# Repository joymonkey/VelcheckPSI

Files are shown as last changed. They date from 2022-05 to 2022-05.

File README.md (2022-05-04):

# Velcheck PSI Reproduction Project

**PSI** : Process State Indicator, the round color light seen on R2-D2's dome (one blue/red in front, one yellow/green in rear)

**Velcheck** : Pioneering member of the R2 Builders Club, 80's synth virtuoso

In the early days of the R2 Builders, Mike Velcheck designed and supplied a PSI for club members around the world. His design has been the basis for most PSI's since, all sharing the same footprint, many with an abundance of LEDs and fancy swipe animations, none as simple and plug-n-play friendly as Mikes. In December of 2021 Mike passed away.

This project aims to bring back Mike Velcheck's great PSI design, so that it may continue to make its way into droids. Using a donor unit, I reverse clumgeneered Mike's PCB, making a couple of very minor tweaks to the layout. An unused capacitor was removed, in it's place is a powerful Devo Energy Dome (a nod to Mike's involvement with RadioStar Band). The resulting Eagle PCB and schematic files are found within this repository, along with gerber files for production, firmware .bin and Mike's own instruction manual.

**Usage** 

See Mike's PDF user guide in this repository.

**Through-Hole Assembly**

The boards come partially assembled, but the through-hole components will need to be soldered in place. Before starting, you should decide on your LED layout (see Checkerboard vs Side by Side beloe).

 * Being mindful of polarity and color placement, each LED can then be soldered in place.
 * Next, you'll want to solder the 8-pin IC socket, which the PIC MCU (U1) will eventually sit in.
 * Solder the jumper pins for JP1 and JP2.
 * Solder the 2-pin and 4-pin screw terminals.
 * Carefully insert the pre-programmed PIC MCU into its socket.

To test, apply 12V to the 2-pin screw terminal (being mindful of polarity). 

**Checkerboard vs Side by Side?**

By moving two resistors on the board, it can be configured with LEDs in a checkerboard layout (giving a better 'spead' of each color), or side-by-side layout (which allows the PSI to appear 'stuck' with both red and blue lit at the same time). The board uses 220 ohm ressitors to limit current to each branch of 3 LEDs. For checkerboard layout, R9 and R10 should not be populated. For side-by-side layout, R8 and R5 should not be populated.

**Using with JEDI Displays**

The PIC IC can be removed, and two wires run from a JEDI Display controller. This allows the JEDI Display to set the PSI's to their specific colors (useful during animations) rather than the onboard PIC.

**Bill Of Materials**

The kit should coime will all parts needed, but if you'd like to build from scratch, here is a BOM for all parts. For LEDs, high brightness and 120 degree viewing angle is recommended. For standard R2-D2 colors, you'll need 6 red, 6 blue, 6 yellow, 6 green. In the US, SuperBrightLEDs sell suitable 5m LEDs for about 50c each. These offer better spread of color than typical cheap 5mm LEDs.

 * U1 : PIC10F202-I/P 8-bit MCU (typically in an )
 * U2 : AS78L05RTR-E1 5V LDO
 * C2 : 330nf 50V 0805 X7R capacitor
 * C3 : 100nf 50V 0805 X7R capacitor
 * R1, R2 : 10K ohm 0603 resistor
 * R3, R6 : 3.3K ohm 0603 resistor
 * R4, R5, R7, R8 : 220 ohm 0603 resistor
 * D1-D12 : 5mm LEDs, various colors
 * D13 : 1N4001 diode
 * Q1, Q2 : MBT2222A BJT NPN transistor
 * P1 : 2-pin 2.54mm pitch screw terminal
 * P2 : 4-pin 2.54mm pitch screw terminal
 * JP1 & JP2 : 2.54mm 2-row 2-column male pin header

**Firmware**

The firmware .bin file in this repository was copied directly from one of Mike's PSI's. Unfortunately source code is unavailable. To program a blank PIC IC, you'll need a programmer such as a PicKit3.

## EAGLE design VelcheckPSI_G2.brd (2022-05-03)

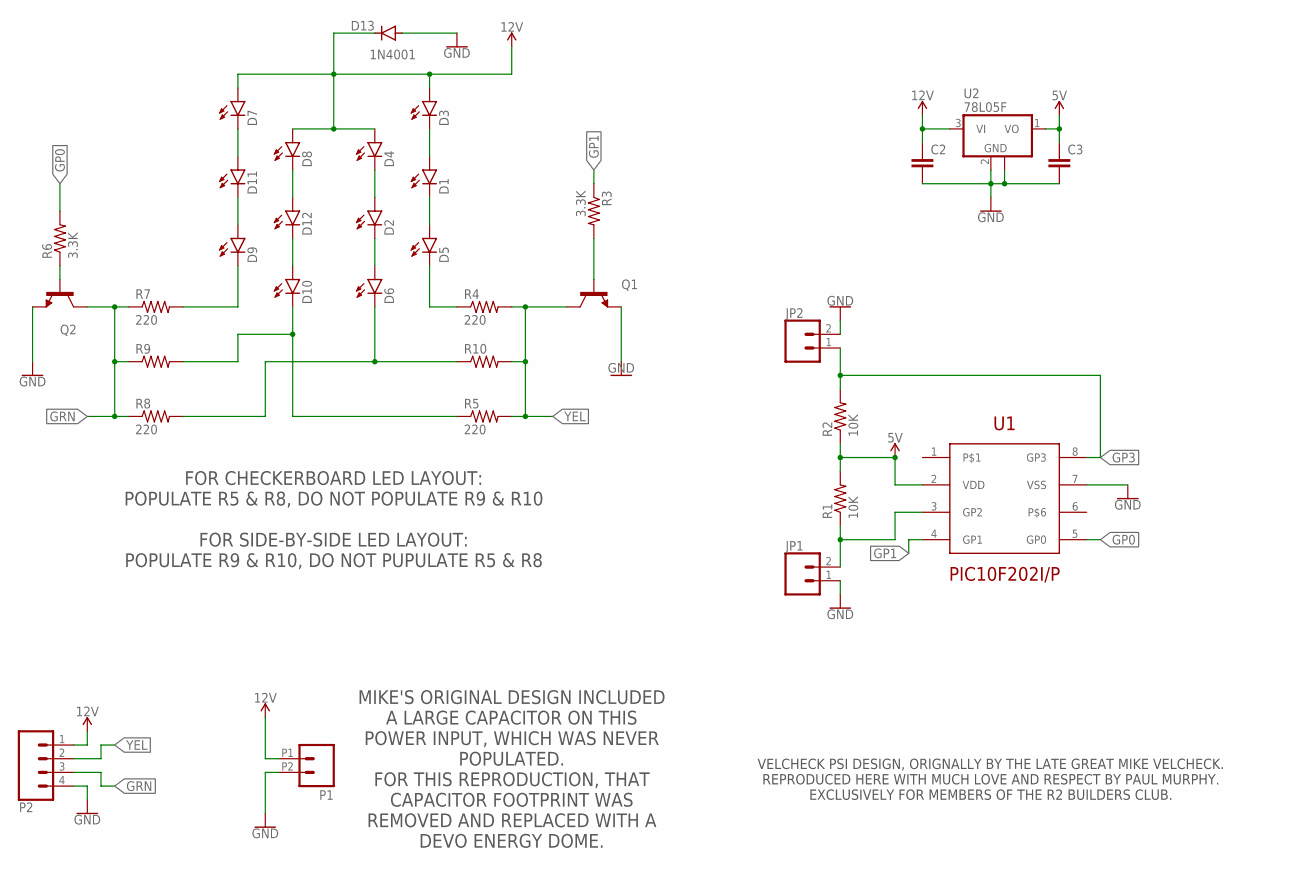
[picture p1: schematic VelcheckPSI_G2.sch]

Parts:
C2, C3: C-EUC0805; C0805
D1, D2, D3, D4, D5, D6, D7, D8, D9, D10, D11, D12: LED5MM; LED5MM_SLIM
D13: 1N4001; DO-214AC
JP1, JP2: CONN_02; 1X02
P1: M022.54MM_SCREWTERM; 1X02_2.54_SCREWTERM
P2: CONN_04POLAR; MOLEX-1X4
Q1, Q2: MMBT2222ALT1-NPN-SOT23-BEC; SOT23-BEC
R1, R2: 10K; R0603
R3, R6: 3.3K; R0603
R4, R5, R7, R8: 220; R0603
R9, R10: R-US_R0603; R0603
U1: PIC10F202I/P; DIP762W53P254L949H508Q8B
U2: 78L05F; SOT89

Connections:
5V: C3.1, R1.2, R2.1, U1.2 (VDD), U2.1 (VO)
12V: C2.1, D3.A, D4.A, D7.A, D8.A, D13.C, P1.P1 (1), P2.1, U2.3 (VI)
GND: C2.2, C3.2, D13.A, JP1.1, JP2.2, P1.P2 (2), P2.4, Q1.E, Q2.E, U1.7 (VSS), U2.2 (GND), U2.2@1 (GND)
GP0: R6.2, U1.5 (GP0)
GP1: R3.1, U1.4 (GP1)
GP3: JP2.1, R2.2, U1.8 (GP3)
GRN: P2.3, Q2.C, R7.1, R8.1, R9.1
unnamed: Q2.B, R6.1
unnamed: Q1.B, R3.2
unnamed: JP1.2, R1.1, U1.3 (GP2)
unnamed: D5.K (C), R4.1
unnamed: D9.K (C), R7.2
unnamed: D10.K (C), R5.1, R9.2
unnamed: D1.A, D3.K (C)
unnamed: D2.A, D4.K (C)
unnamed: D1.K (C), D5.A
unnamed: D2.K (C), D6.A
unnamed: D6.K (C), R8.2, R10.1
unnamed: D7.K (C), D11.A
unnamed: D9.A, D11.K (C)
unnamed: D8.K (C), D12.A
unnamed: D10.A, D12.K (C)
YEL: P2.2, Q1.C, R4.2, R5.2, R10.2

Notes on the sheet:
FOR CHECKERBOARD LED LAYOUT: POPULATE R5 & R8, DO NOT POPULATE R9 & R10 FOR SIDE-BY-SIDE LED LAYOUT: POPULATE R9 & R10, DO NOT PUPULATE R5 & R8
MIKE'S ORIGINAL DESIGN INCLUDED A LARGE CAPACITOR ON THIS POWER INPUT, WHICH WAS NEVER POPULATED. FOR THIS REPRODUCTION, THAT CAPACITOR FOOTPRINT WAS REMOVED AND REPLACED WITH A DEVO ENERGY DOME.
VELCHECK PSI DESIGN, ORIGNALLY BY THE LATE GREAT MIKE VELCHECK. REPRODUCED HERE WITH MUCH LOVE AND RESPECT BY PAUL MURPHY. EXCLUSIVELY FOR MEMBERS OF THE R2 BUILDERS CLUB.

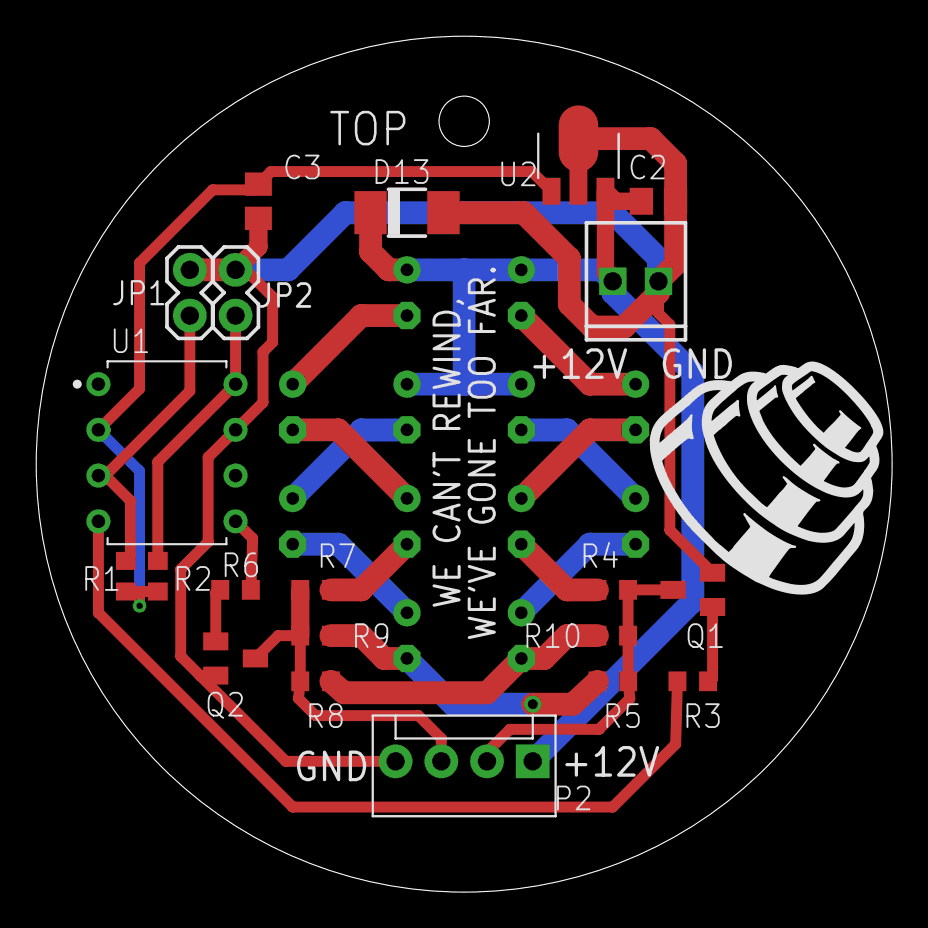
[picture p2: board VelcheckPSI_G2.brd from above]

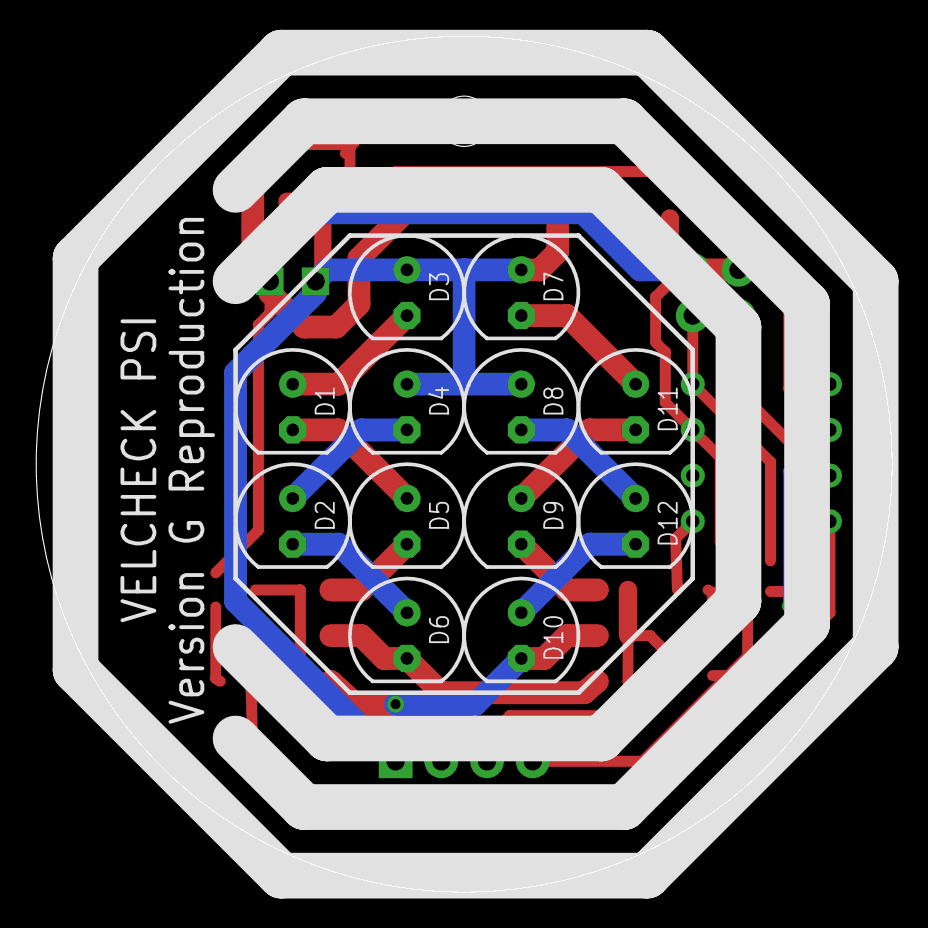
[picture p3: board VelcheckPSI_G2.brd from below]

Board: 2 copper layers, 47.5 x 47.5 mm, 34 parts (12 on the bottom side), 23 nets.

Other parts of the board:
U$1: DEVO

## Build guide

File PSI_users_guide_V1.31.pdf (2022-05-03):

# PSI User's Guide

Version 1.31
February 5, 2008
Mike Velcheck

# 1. Introduction

Thank you for purchasing my "Astromech PSI Kit." These boards are my first electronic contribution to the R2 Builders Club. They were designed with several goals in mind:
1) To create PSIs with a "random-looking" flash pattern
2) To create PSIs which can flash or fade
3) To use high-brightness LEDs
4) To use wide-angle LEDs to minimize "hot spots"
5) To create round PSI boards that can be mounted in a tube
6) To create a fully assembled kit for less than $50, including domestic shipping

# 2. Getting started

Required Tools and materials:
- Small common screwdriver
- Wire strippers
- Wire cutters
- 12V DC source (battery or DC power supply)

Kit Contents:
Your PSI kit contains two PSIs, mode selection shunts (jumpers), and connection wires.

In a standard PSI kit, the front (red/blue) PSI contains the "brains" of the system, and will be referred to as the "master" PSI. The rear (yellow/green) PSI does not contain any control electronics, and is referred to as the "slave" PSI.

The wires have been twisted to form two cables. A standard PSI kit contains a two-wire (red & black)
POWER CABLE and a three-wire (red, yellow, and green) MASTER/SLAVE CABLE.

The shunts are used to control the operating mode of the PSIs, and will be explained in more detail later.

## 2a. Connecting the front and rear PSIs

The front (red/blue) PSI contains the "brains" of the system, and will be referred to as the "master" PSI. The rear (yellow/green) PSI does not contain any control electronics, and is referred to as the "slave" PSI.

PSI User's Guide | Page 1 of 6

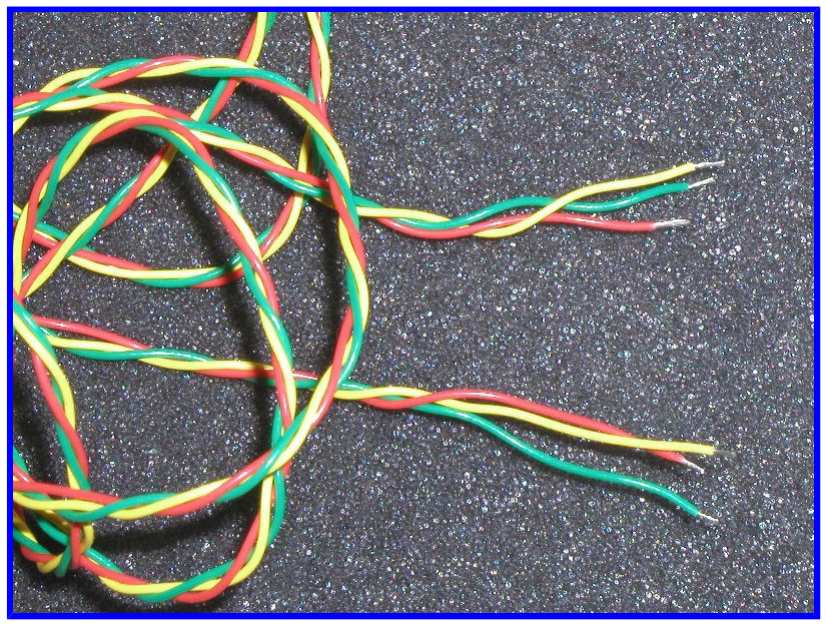
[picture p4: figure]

1) Strip off about 1/8" of insulation from all three wires on both ends of the MASTER/SLAVE CABLE:
2) Loosen the terminals of the four pin connector (J2) on both the MASTER board and the
SLAVE board by turning the screws counter-clockwise.

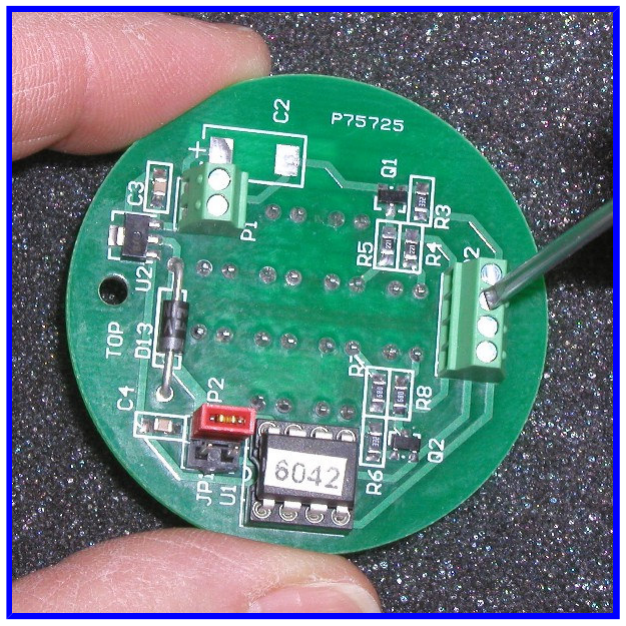
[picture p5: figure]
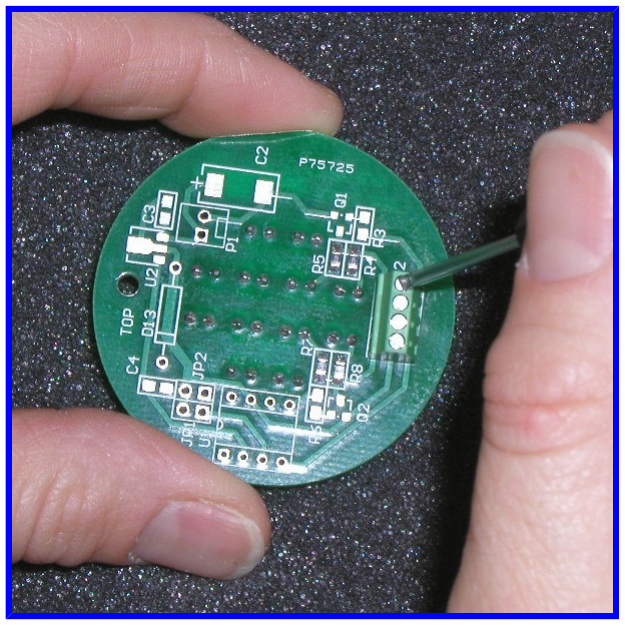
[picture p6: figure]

Master Board | Slave Board
3) Insert the stripped wires into the four pin connector (J2) on the MASTER board and tighten the screw terminals by turning the screws clockwise.

Be sure to match the color and location of each wire (RED, YELLOW, GREEN, NONE) in the picture. Note that the fourth position ("GND") is not used.

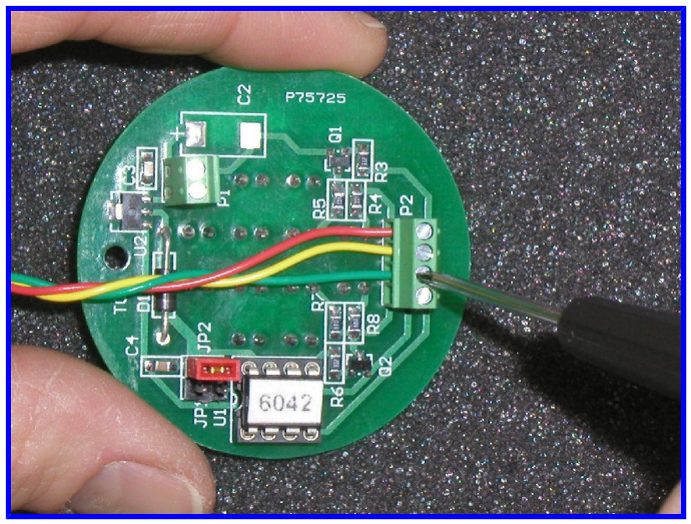
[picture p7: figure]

Master Board

4) Repeat for the matching connector (J2) on the SLAVE board, making certain that the wire locations match in both connectors. Again, note that the fourth position ("GND") is not used.

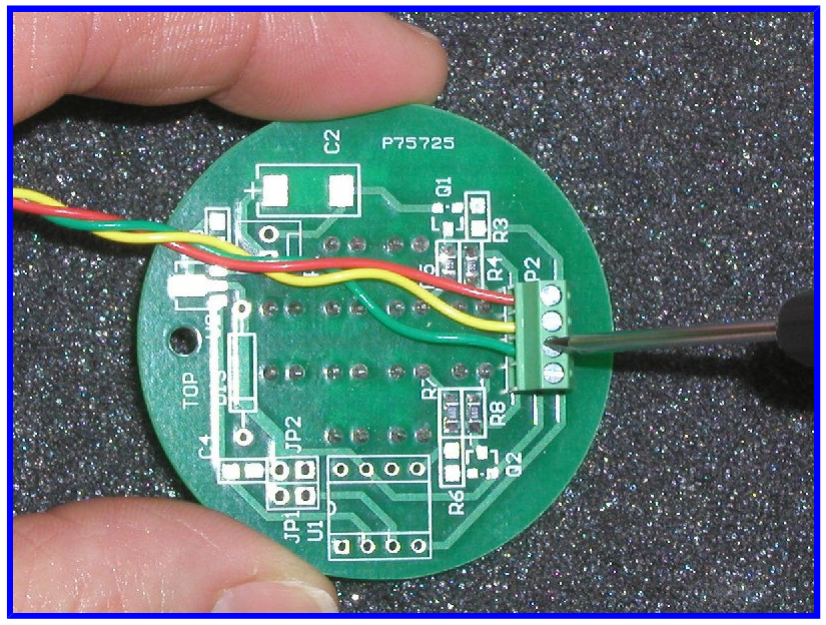
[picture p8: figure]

Slave Board

PSI User's Guide | Page 2 of 6

WARNING!

Never connect a "master" board to another "master" board. If your kit contains two master boards, you should connect each board to a power source, and not to the other board. I don't believe that anything will fry, but you'll be attempting to drive the LEDs from two different sources.

## 2b. Connecting the Power Cable

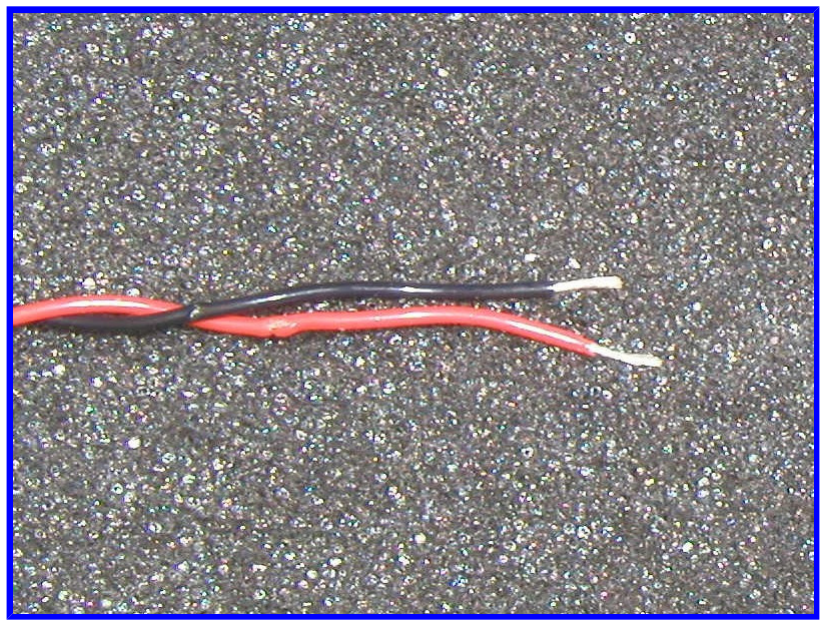
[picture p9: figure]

1) Strip off about 1/8" of insulation from both wires on one end of the POWER CABLE:

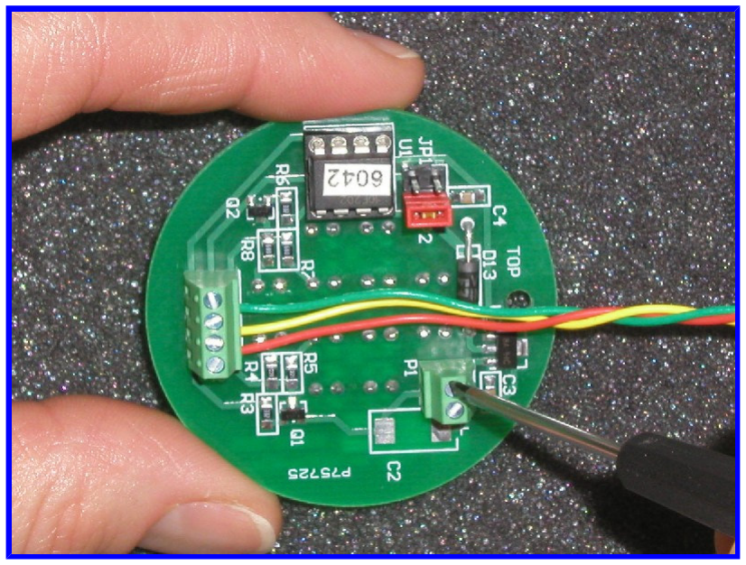
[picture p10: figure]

2) Loosen the terminals of the two-pin connector (J1) on the MASTER board by turning the screws counter-clockwise.
3) Insert the stripped wires (RED = +12V, BLACK = GND) into the two-pin connector (J1) on the MASTER board and tighten the screw terminals by turning the screws clockwise.

Be sure to match the color and location of each wire (RED, BLACK) in the picture.

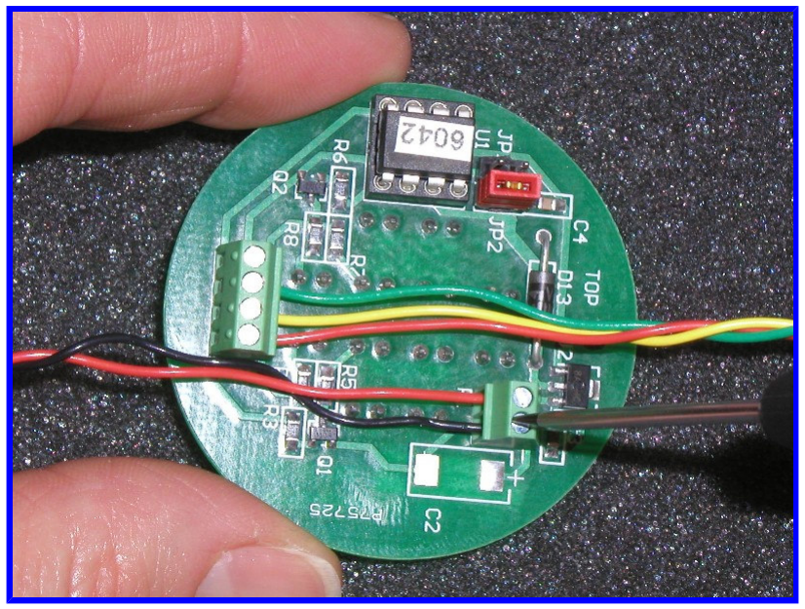
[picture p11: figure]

4) Strip off the insulation from the other end of the power cable to suit your wiring configuration.
5) Connect the stripped wires to the battery or DC power source, making sure that the RED wire is connected to +12V (or BATTERY+), and the BLACK wire is connected to GROUND (or BATTERY-).
PSI User's Guide | Page 3 of 6

# 3. Operating Modes

These PSIs use a microcontroller to control the flash rate and pattern, to create a psudo-random behavior. The boards can operate in one of four modes, controlled by installing different combinations of shunts on jumpers JP1 and JP2. The four modes of operation are:

1) FLASH mode (no shunts) - colors change by blinking back and forth.
2) FADE mode (shunt on JP1) - colors change by fading back and forth.
3) FLASH+FADE (mixed) mode (shunt on JP2) - colors change by a combination of blinking and fading.
4) TEST mode (shunts on JP1 and JP2) - colors FLASH slowly, to allow you to verify each LED is operating properly, or to help with placement of diffuser material.

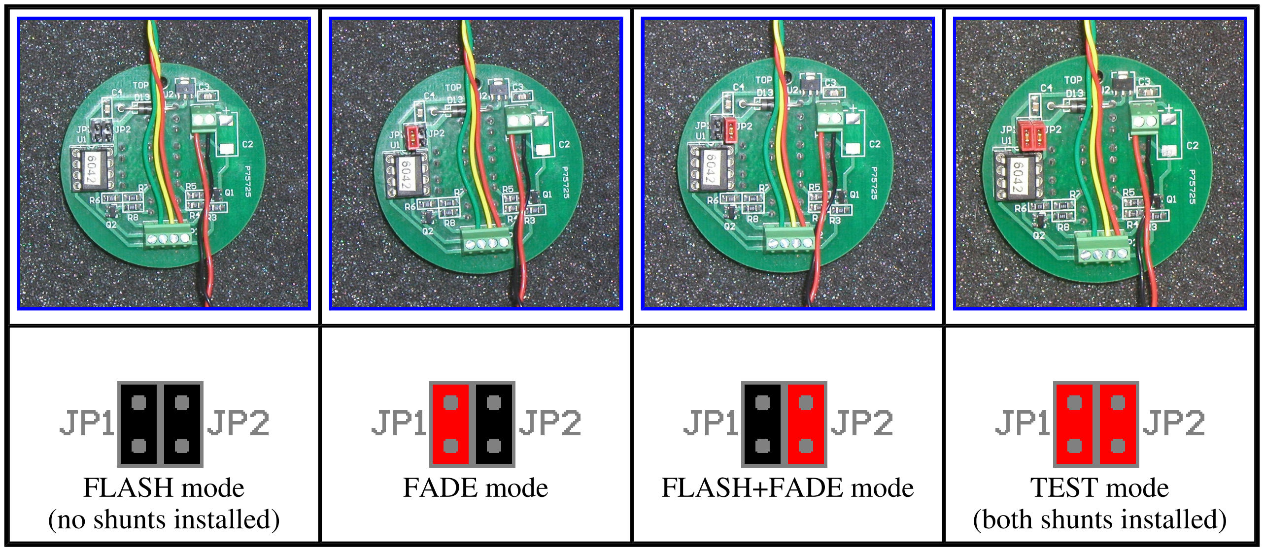
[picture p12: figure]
FLASH mode (no shunts installed); FADE mode; FLASH+FADE mode; TEST mode (both shunts installed)

Note: Shunts are shown in RED. Your shunts may be a different color.

In all cases, you'll need to remove power from the board and power it back on again for the new jumper setting to take effect. The PSIs typically ship with shunts installed for "mixed" mode (FLASH+FADE), with a spare shunt on one of the pins (or in the bag) for storage.

6) The properly connected PSIs will blink three times, then begin sequencing the LEDs in the selected operating mode.

WARNING!

These boards are designed for 12V power. Using less that 12V will reduce the brightness of the LEDs. Using greater than 12V will overdrive the LEDs, and may cause permanent damage.

PSI User's Guide | Page 4 of 6

# 4. Mounting Considerations

Each PSI board is 1.875" (1 7/8") in diameter, and there should be sufficient clearance to the board edge to allow for a tube with a 1.75" (1/ 3/4") inner diameter to butt up against the board.
I've found several pieces of PVC tube that work pretty well. I also went to onlinemetals.com and ordered aluminum tube that was (if memory serves)
2.00" OD, 0.058" wall thickness and
1.875 OD, 0.058" wall thickness
This should allow the smaller tube to fit inside the larger tube, and be used as a "spacer" between the PCB and any diiffuser material that one might choose to use. However, I haven't built one up like this yet, so I'm still talking "in theory".

# 5. Board Versions and Revisions

Each PSI board has a label indicating the version and revision of the board. Most kits ship with a red/blue master board and a yellow/green slave board. However, the exact version and revision of each board depends on when the board was made, what connectors are being used, whether it's a master or a slave board, and the LED configuration for the board. The table below summarizes all currently available versions and revisions.

VERSION REVISION MASTER/SLAVE LED
COLORS

LED
ARRANGEMENT PCB CONECTOR TYPE

SUB-
R2001-A | 00 | Master | Red/Blue | Left/Right | A

Molex latching
(white or brown)
SUB-
R2001-A | 01 | Master | Red/Blue | Left/Right | A

Phoenix (green
w/screw terminals)
SUB-
R2001-A | 02 | Master | Yellow/Green | Left/Right | B

Phoenix (green
w/screw terminals)
SUB-
R2001-B | 00 | Slave | Yellow/Green | Left/Right | A

Molex latching
(white or brown)
SUB-
R2001-B | 01 | Slave | Yellow/Green | Left/Right | A

Phoenix (green
w/screw terminals)
SUB-
R2001-B | 02 | Slave | Yellow/Green | Left/Right | B

Phoenix (green
w/screw terminals)
SUB-
R2001-C | 00 | Master | Yellow/Green | Left/Right | A

Molex latching
(white or brown)
SUB-
R2001-C | 01 | Master | Yellow/Green | Left/Right | A

Phoenix (green
w/screw terminals)
SUB-
R2001-D | 00 | Slave | Yellow/Green | checkerboard | B

Phoenix (green
w/screw terminals)
SUB-
R2001-E | 00 | Master | White/Green | Left/Right | A

Phoenix (green
w/screw terminals)
SUB-
R2001-F | 00 | Slave | White/Green | Left/Right | A

Phoenix (green
w/screw terminals)
SUB-
R2001-G | 00 | Master | Red/Blue | checkerboard | B

Phoenix (green
w/screw terminals)
PSI User's Guide | Page 5 of 6

# 6. Additional Information & Feedback

For the latest versions of this document, go to http://www.radiostarband.net/r2-d2/index.html and follow the links to the PSI page. The online html version contains links to larger images as well.

I'm interested in hearing your comments, complaints, and suggestions. If you have any "out of the ordinary" requests (different flash rates or patterns, different colors, etc.), get in touch to discuss what you'd like to do.

# 7. Document History

VERSION | DESCRIPTION

### 1.0 Initial Release 1.1 Added wiring instructions for screw terminal connectors

1.2 Corrected photo and text in section 2a., step 3. 1.3 Added board versions and revisions to section 5. 1.31 Added version "G" board to section 5.

PSI User's Guide | Page 6 of 6

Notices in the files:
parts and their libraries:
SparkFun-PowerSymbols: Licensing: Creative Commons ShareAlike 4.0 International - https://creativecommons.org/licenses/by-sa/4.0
